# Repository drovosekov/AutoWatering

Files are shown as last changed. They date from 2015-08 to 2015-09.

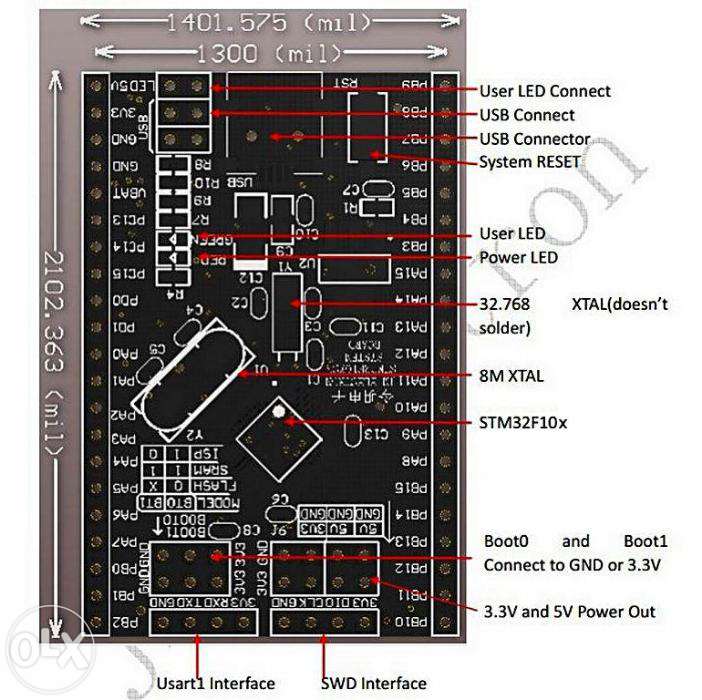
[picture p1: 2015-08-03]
PCB/mans/STM32F10XC8 system board/stm32f100-arm-development-board-elektronika.jpg

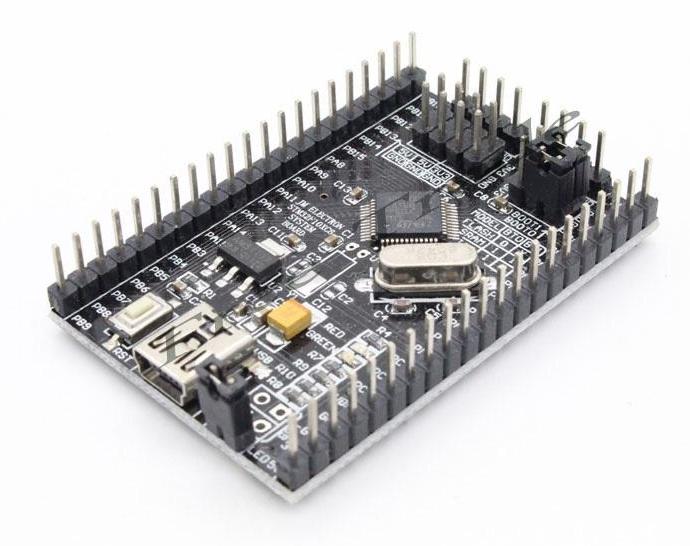
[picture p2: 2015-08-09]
PCB/mans/STM32F10XC8 system board/stm32f100c8t6-stm32f100-stm32f1-stm32-minimum.jpg

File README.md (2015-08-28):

# AutoWatering

Система автополива для цветов на базе МК STM32 и экрана 16х2

## Возможности

- часы реального времени
- контроль уровня воды в баке
- контроль температуры воздуха
- контроль влажности грунта
- управление внешней подсветкой для увеличения светового интервала в задаваемый промежуток времени
- настраиваемый интервал времени суток для полива
- продвинутый алгоритм анализа влажности земли: летом полив вечером, зимой полив утром. При температуре воздуха больше +30С - полив не зависит от вермени дня, но в заданный разрешенный промежуток времени. Настраиваемая продолжительность отсрочки перед поливом, для исключения переувлажнения грунта
- ручной режим полива: активируется в меню на 3 минуты, после чего система вновь переводится в автоматический режим
- отображение информации в режиме ожидания: температура воздуха, влажность грунта, текущее время, время оставшееся до проверки датчика влажности или до начала полива, уровень заряда резервного аккумулятора, контроль воды в резервуаре
- резервное питание от аккумулятора 7А/ч
- встроенный блок зарядки аккумулятора

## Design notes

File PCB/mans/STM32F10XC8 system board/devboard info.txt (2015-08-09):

Отладочная плата STM32F100C8T6

Корпус: LQFP48
64kB Flash и 20kB RAM;
Внешнее питание: +5В (USB mini)
Бортовой стабилизатор: 3v3 (AMS 1117 3.3)
Кварц: 8MГц;
Светодиод питание = RED;
Светодиод пользовательский = GREEN, PA1 (включается джампером)
Кнопка ресет = RST;
Доступны порты:
PA0 .. PA15
PB0 .. PB15
PC13, PC14, PC15
PD0, PD1 (кварц 8МГц)
PB3, PB4, PA13, PA14, PA15 - заняты JTAG-ом (но их можно освобождать ремапом)
Джампера BOOT0 и BOOT1 выбора типа загрузки: Flash, SRAM, ISP (default boot0 и boot1 на GND)
Основные интерфейсы сгруппированы:
UART1 = 3v3 - RxD(PA10) - TxD(PA9) - GND
SWD = 3v3 - DIO(PA13) - CLK(PA14) - GND 
Зарезервировано место под часовой кварц и его кондеры (PC14 и PC15)

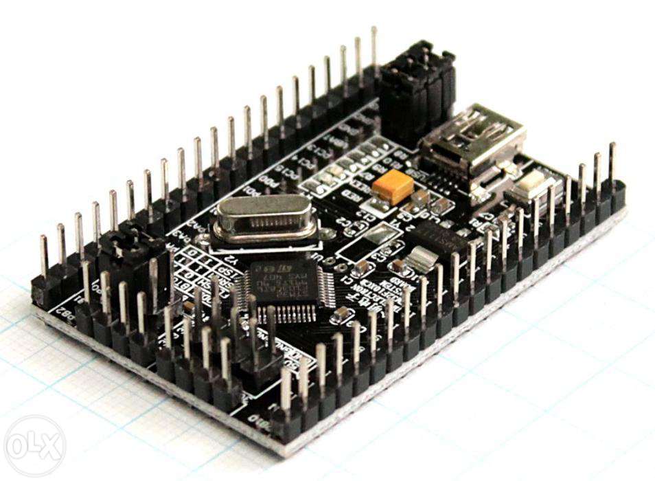
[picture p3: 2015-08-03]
PCB/mans/STM32F10XC8 system board/stm32f100-arm-development-board.jpg

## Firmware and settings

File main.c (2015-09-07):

#include "main.h"

static void init_all(void);
static void init_default_values(void);

//--глобальные переменные--------
display_regim regim;
//-------------------------------

int main(void)
{
	init_all();

    while (1)
    {
    	get_buttons_state();
    	get_sensors_state();

    	switch(regim){
		case DISPLAY_REGIM_WATERING:
		case DISPLAY_REGIM_MANUAL_WATERING:
    	case DISPLAY_REGIM_DEFAULT:
    	case DISPLAY_REGIM_NO_WATER:
    		display_default_draw();
			break;

    	case DISPLAY_REGIM_MENU:
    		TIM_Cmd(TIM7, DISABLE);
    		display_menu_draw();
    		break;

    	case DISPLAY_REGIM_SET_TIME_DATE:
    		display_set_date_time_draw();
    		break;

    	case DISPLAY_REGIM_SET_WATERING_TIME:
    		display_set_watering_time_draw();
    		break;

    	case DISPLAY_REGIM_SET_WAERING_DUR:
    		display_set_watering_duration_draw();
    		break;

    	case DISPLAY_REGIM_SET_HUMIDITY:
    		display_set_humidity_draw();
    		break;

    	case DISPLAY_REGIM_SET_CHK_INTERVAL:
    		display_set_chk_interval_draw();
    		break;

    	case DISPLAY_REGIM_SET_WATERING_REG:
    		display_set_watering_reg_draw();
    		break;

    	case DISPLAY_REGIM_SET_LIGHT:
    		display_set_light_time_draw();
    		break;

    	case DISPLAY_REGIM_SET_BRIGHT_CONTR:
    		display_set_bright_contrast_draw();
    		break;
    	}

    	auto_bright_off();
    	auto_exit_from_menu();
    }

	return 0;
}

//инициализируем параметры, при первом включении
void init_default_values(void){
	u16 result = BKP_ReadBackupRegister(WATERING_DURATION_BKP);

	if(result == 0){
		/* Allow access to BKP Domain */
		PWR_BackupAccessCmd(ENABLE);
		/* Reset Backup Domain */
		BKP_DeInit();

		//продолжительность полива (сек)
		result=5;
		BKP_WriteBackupRegister(WATERING_DURATION_BKP, result);

		//интервал опроса датчиков
		BKP_WriteBackupRegister(CHECK_INTERVAL_BKP, result);

		result = set_low_n_height(10, 60);//мин.влажность (%) и задержка перед поливом (мин)
		BKP_WriteBackupRegister(HUMYDURTY_BKP, result);

		result = set_low_n_height(9, 0);//утро (час, мин)
		BKP_WriteBackupRegister(tMORNING_WATERING_TIME_BKP, result);
		result = set_low_n_height(18, 0);//вечер (час, мин)
		BKP_WriteBackupRegister(tEVENING_WATERING_TIME_BKP, result);

		result = set_low_n_height(16, 13);//подсветка/контраст
		BKP_WriteBackupRegister(BRIGHT_CONTRAST_BKP, result);
		TIM_SetCompare3(TIM3, 10 * 4095); //подсветка
		TIM_SetCompare4(TIM3, 13 * 4095); //контраст

		result = set_low_n_height(8, 0);//досветка утро
		BKP_WriteBackupRegister(tMORNING_LIGHT_TIME_BKP, result);
		result = set_low_n_height(21, 0);//досветка вечер
		BKP_WriteBackupRegister(tEVENING_LIGHT_TIME_BKP, result);
		BKP_WriteBackupRegister(ACTIVE_LIGHT_TIME_BKP, true);//досветка активна

		/* Adjust time by values entered by the user*/
		RTCTIME newtime;
		newtime.year =  2015;
		newtime.month = 5;
		newtime.mday =  3;
		newtime.hour =  15;
		newtime.min =   30;
		RTC_SetTime(&newtime);

		PWR_BackupAccessCmd(DISABLE);
	}
}

void init_bright_contrast(void){
	u16 result = BKP_ReadBackupRegister(BRIGHT_CONTRAST_BKP);
	TIM_SetCompare3(TIM3, get_height(result) * 4095); //подсветка
	TIM_SetCompare4(TIM3, get_low(result) * 4095);    //контраст
}

void init_all(void){
	SystemInit();

	//configure SysTimer to 1 ms
	while(SysTick_Config(SystemCoreClock / 2400));

	mcu_gpio_deinit();

	lcd_init();

	OW_Init();

	//set DS18B20 resolution 9bit
	u8 cmd[] = {0xCC, 0x4E, 0, 0, DS18B20_RESOLUTION, 0x48};
	OW_Send(OW_SEND_RESET, cmd, sizeof(cmd), 0, 0, OW_NO_READ);

	init_adc();

	init_tim();

	init_default_values();

	init_display_default();

	init_bright_contrast();

	init_rtc();

    regim = DISPLAY_REGIM_DEFAULT;

	TIM_Cmd(TIM7, ENABLE);
}

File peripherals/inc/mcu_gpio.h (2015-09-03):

/*
 *	File:	GPIO.h
 *	Date:	07.01.2011
 */

#ifndef MCU_GPIO_H_
#define MCU_GPIO_H_

void mcu_gpio_deinit();
buttons get_keyboard_state();

/////should be defined by user /////

/* DS18B20 gpio defines */
//#define SENS_2WIRE - not yet tested
#define SENS_3WIRE
#define DS18B20_RESOLUTION	DS18B20_9BIT

#define DS18B20_1WIRE_PORT	A, 9,  HIGH, ALTERNATE_OUTPUT_PUSH_PULL, SPEED_10MHZ //1-wire DS18B20
/* end DS18B20 gpio defines */

/* ADC defines */
#define ADC_CH0				A, 0, HIGH, ANALOG, SPEED_2MHZ //датчик влажности грунта
#define ADC_CH1				A, 7, HIGH, ANALOG, SPEED_2MHZ //уровень заряда аккумулятора
/* end ADC defines */

/* buttons defines */
#define BUTTONS_PIN_A2		A, 2, HIGH, INPUT_PULL_UP, SPEED_2MHZ
#define BUTTONS_PIN_A3		A, 3, HIGH, INPUT_PULL_UP, SPEED_2MHZ
#define BUTTONS_PIN_A4		A, 4, HIGH, INPUT_PULL_UP, SPEED_2MHZ

#define LIGHT_SENSOR		A, 5, HIGH, INPUT_PULL_DOWN, SPEED_2MHZ //сенсор освещенности
#define WATER_LEVER_SENSOR	A, 10, HIGH, INPUT_PULL_DOWN, SPEED_2MHZ //сенсор уровня воды (геркон)
/* end buttons defines */

/* out pins defines */
#define USER_LED			A, 1, HIGH, ALTERNATE_OUTPUT_PUSH_PULL, SPEED_10MHZ //user LED on STM32F100C8T6 board

#define HUMIDITY_SENSOR		B, 0, HIGH, GENERAL_OUTPUT_PUSH_PULL, SPEED_2MHZ //питание датчика влажности грунта
//#define BACKLIGHT_PWM		B, 0, HIGH, ALTERNATE_OUTPUT_PUSH_PULL, SPEED_10MHZ //выход TIM3 CH3
#define CONTRAST_PWM		B, 1, HIGH, ALTERNATE_OUTPUT_PUSH_PULL, SPEED_10MHZ //выход TIM3 CH4

#define NO_WATER_LED		B, 2, HIGH, GENERAL_OUTPUT_PUSH_PULL, SPEED_2MHZ //индикатор отсутствия воды в баке
#define WATERING_RELAY		B, 8, HIGH, GENERAL_OUTPUT_PUSH_PULL, SPEED_2MHZ //реле мотора полива
#define LIGHT_RELAY			B, 9, HIGH, GENERAL_OUTPUT_PUSH_PULL, SPEED_2MHZ //реле фоновой подсветки
/* end out pins defines */

/* LCD defines */
#define LCD_RS		15
#define LCD_EN		14
#define LCD_DB4		13
#define LCD_DB5		12
#define LCD_DB6		11
#define LCD_DB7		10

#define LCD_2X16_RS		B, LCD_RS,  HIGH, GENERAL_OUTPUT_PUSH_PULL, SPEED_10MHZ
#define LCD_2X16_E		B, LCD_EN,  HIGH, GENERAL_OUTPUT_PUSH_PULL, SPEED_10MHZ
#define LCD_2X16_DB4	B, LCD_DB4, HIGH, GENERAL_OUTPUT_PUSH_PULL, SPEED_10MHZ
#define LCD_2X16_DB5	B, LCD_DB5, HIGH, GENERAL_OUTPUT_PUSH_PULL, SPEED_10MHZ
#define LCD_2X16_DB6	B, LCD_DB6, HIGH, GENERAL_OUTPUT_PUSH_PULL, SPEED_10MHZ
#define LCD_2X16_DB7	B, LCD_DB7, HIGH, GENERAL_OUTPUT_PUSH_PULL, SPEED_10MHZ

#define LCD_PORT	GPIOB
#define LCD_EN_BC  (BIT(LCD_EN+16))
#define LCD_RS_BC  (BIT(LCD_RS+16))
#define LCD_DB4_BC (BIT(LCD_DB4+16))
#define LCD_DB5_BC (BIT(LCD_DB5+16))
#define LCD_DB6_BC (BIT(LCD_DB6+16))
#define LCD_DB7_BC (BIT(LCD_DB7+16))
#define LCD_ALL_DATA_PINS_OFF	(LCD_DB7_BC | LCD_DB6_BC | LCD_DB5_BC | LCD_DB4_BC)
#define LCD_ALL_PINS_OFF 		(LCD_ALL_DATA_PINS_OFF | LCD_RS_BC | LCD_EN_BC)
/* end LCD defines */

/* backup registers defines */
#define tMORNING_WATERING_TIME_BKP	BKP_DR2	//утреннее время начала разрешенного интервала полива
#define tEVENING_WATERING_TIME_BKP	BKP_DR3	//вечернее время окончания разрешенного интервала полива
#define HUMYDURTY_BKP				BKP_DR4	//минимальный и максимальный уровень влажности для полива
#define CHECK_INTERVAL_BKP			BKP_DR5	//интервал проверки уровня влажности (минут)
#define WATERING_DURATION_BKP		BKP_DR6 //интервал задержки перед поливом (минут)
#define BRIGHT_CONTRAST_BKP			BKP_DR7 //уровни яркости подсветки и контраста
#define tMORNING_LIGHT_TIME_BKP		BKP_DR8	//утреннее время включения доп.подсветки
#define tEVENING_LIGHT_TIME_BKP		BKP_DR9	//вечернее время включения доп.подсветки
#define ACTIVE_LIGHT_TIME_BKP		BKP_DR10//используется досветка
/* end backup registers defines */

///////////////////////////////////

//-----------------------------------------------------------------------------
#define GPIO_PIN_SPEED_2MHZ()	(2UL)
#define GPIO_PIN_SPEED_10MHZ()	(1UL)
#define GPIO_PIN_SPEED_50MHZ()	(3UL)

#define BIT(NUMBER)		(1UL << (NUMBER))
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

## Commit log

2015-08-01 PCB control panel added
2015-08-02 pdf pcb control panel
2015-08-03 optimizations
    PCB control panel - ver 1.1
2015-08-03 revert to ANSI Win-1251 codepage
    CooCox incorrect compile russian characters into flash
    add devboard info
    [default.c, getRegim.c, localize_ru.h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]
2015-08-04 GRB files of PCB
    added files for modeling PCB in 3d and order board on manufacture
    [Main Board-B_Cu.GBL, Main Board-B_Mask.GBO, Main Board-B_Mask.GBS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]
2015-08-06 PCB convert to SprintLayout ver 6
    [Main Board-B_Cu.GBL, Main Board-B_Mask.GBO, Main Board-B_Mask.GBS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]
2015-08-06 PCB ctrl panel update
2015-08-07 add STM32F10X8 sys board SL macros
2015-08-09 convert for STM32F10XC8T6
2015-08-10 PCB main board v1.0
2015-08-10 PCB mainboard upgrade
2015-08-11 PCB upgrade
2015-08-13 PCB ugrade
2015-08-14 correct gpio and PCB mainboard
    [mcu_gpio.h]
2015-08-18 PCB main board v1,1
    replace relay to mosfet transistors for control watering motor and
    additional lighting
    [mcu_gpio.h]
2015-08-20 PCB main board complite
2015-08-28 PCBs update
2015-08-31 PCB update
2015-09-03 PCB update, pins reconfig
2015-09-07 new version PCB
    without LM317
2015-09-20 main board PCB ver 1.3
    add SEP-05 module Wi-Fi
    optimizatons
2015-09-20 PCB optz
2015-09-21 PCB upd
2015-09-24 PCB much perfect
2015-10-13 PCB realese ver
